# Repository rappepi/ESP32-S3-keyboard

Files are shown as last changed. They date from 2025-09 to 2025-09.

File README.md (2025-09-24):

# ESP32-S3-keyboard

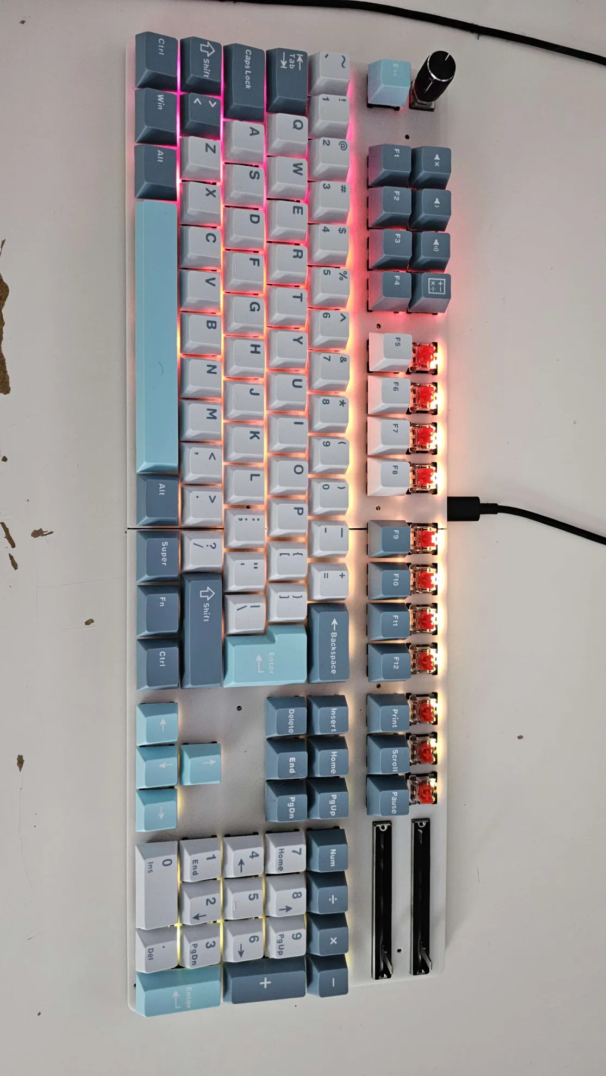
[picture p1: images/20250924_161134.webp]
PCB front view

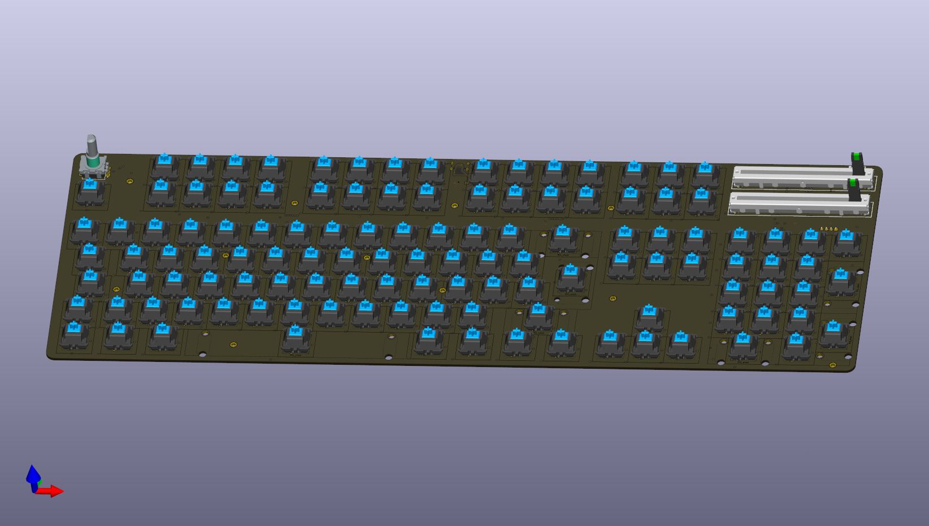
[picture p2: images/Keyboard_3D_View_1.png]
PCB 3D view 1

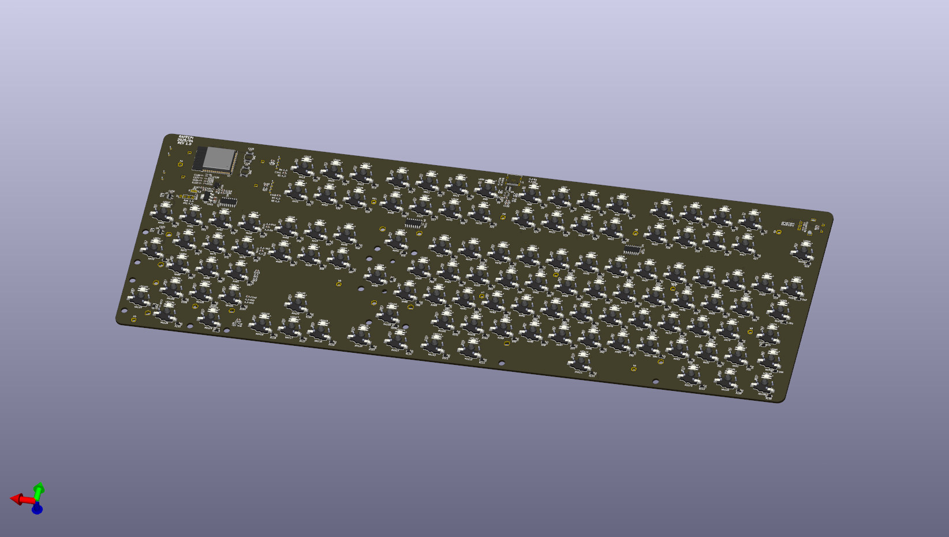
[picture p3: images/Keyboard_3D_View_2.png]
PCB 3D view 2


This project is licensed under the [Creative Commons Attribution-NonCommercial 4.0 International (CC BY-NC 4.0)](https://creativecommons.org/licenses/by-nc/4.0/).  
You are free to use, modify, and share the project as long as it is **not for commercial use** and **you give appropriate credit** to the original author.



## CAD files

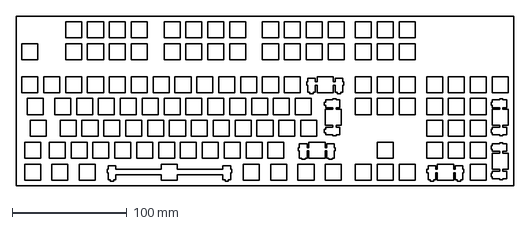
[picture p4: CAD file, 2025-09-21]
keyboard plate.dxf
433.6 x 147.8 mm

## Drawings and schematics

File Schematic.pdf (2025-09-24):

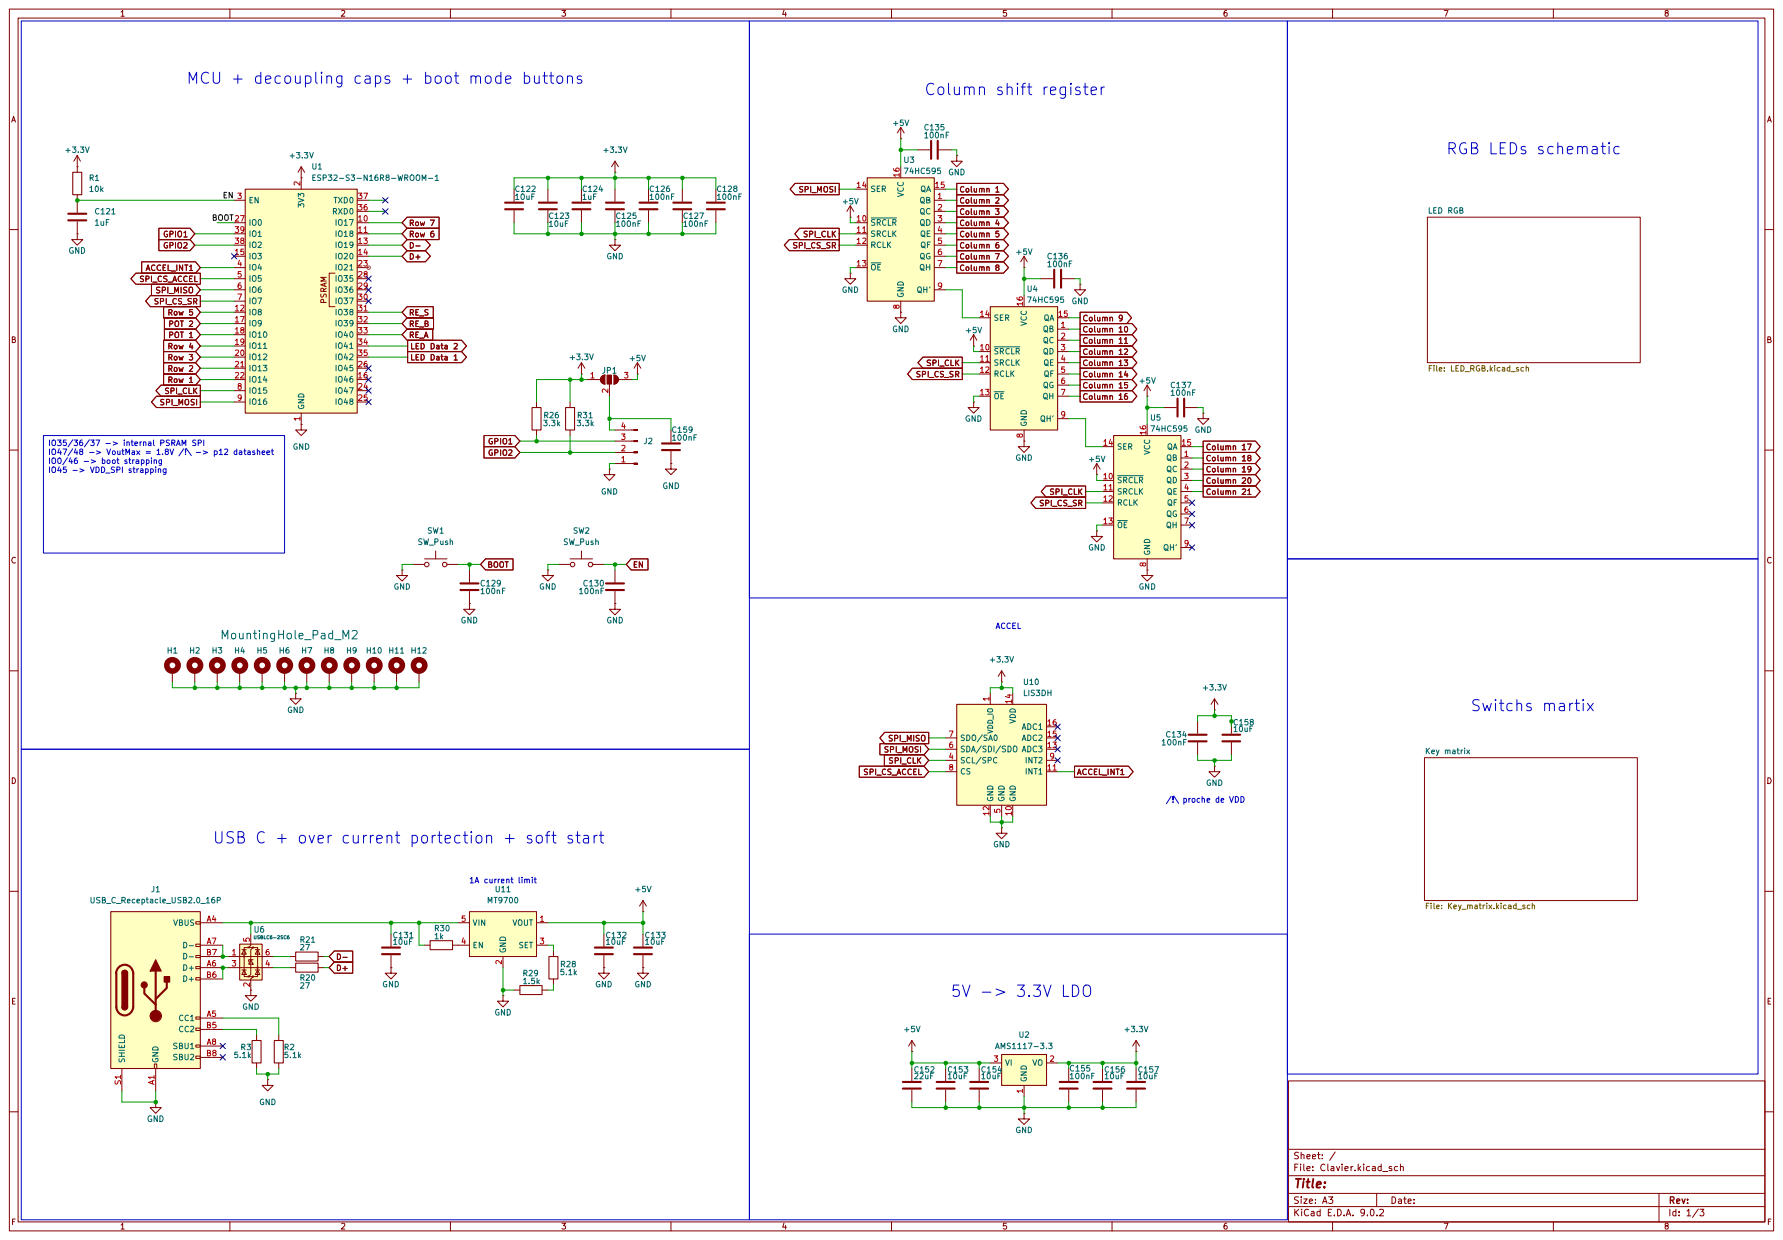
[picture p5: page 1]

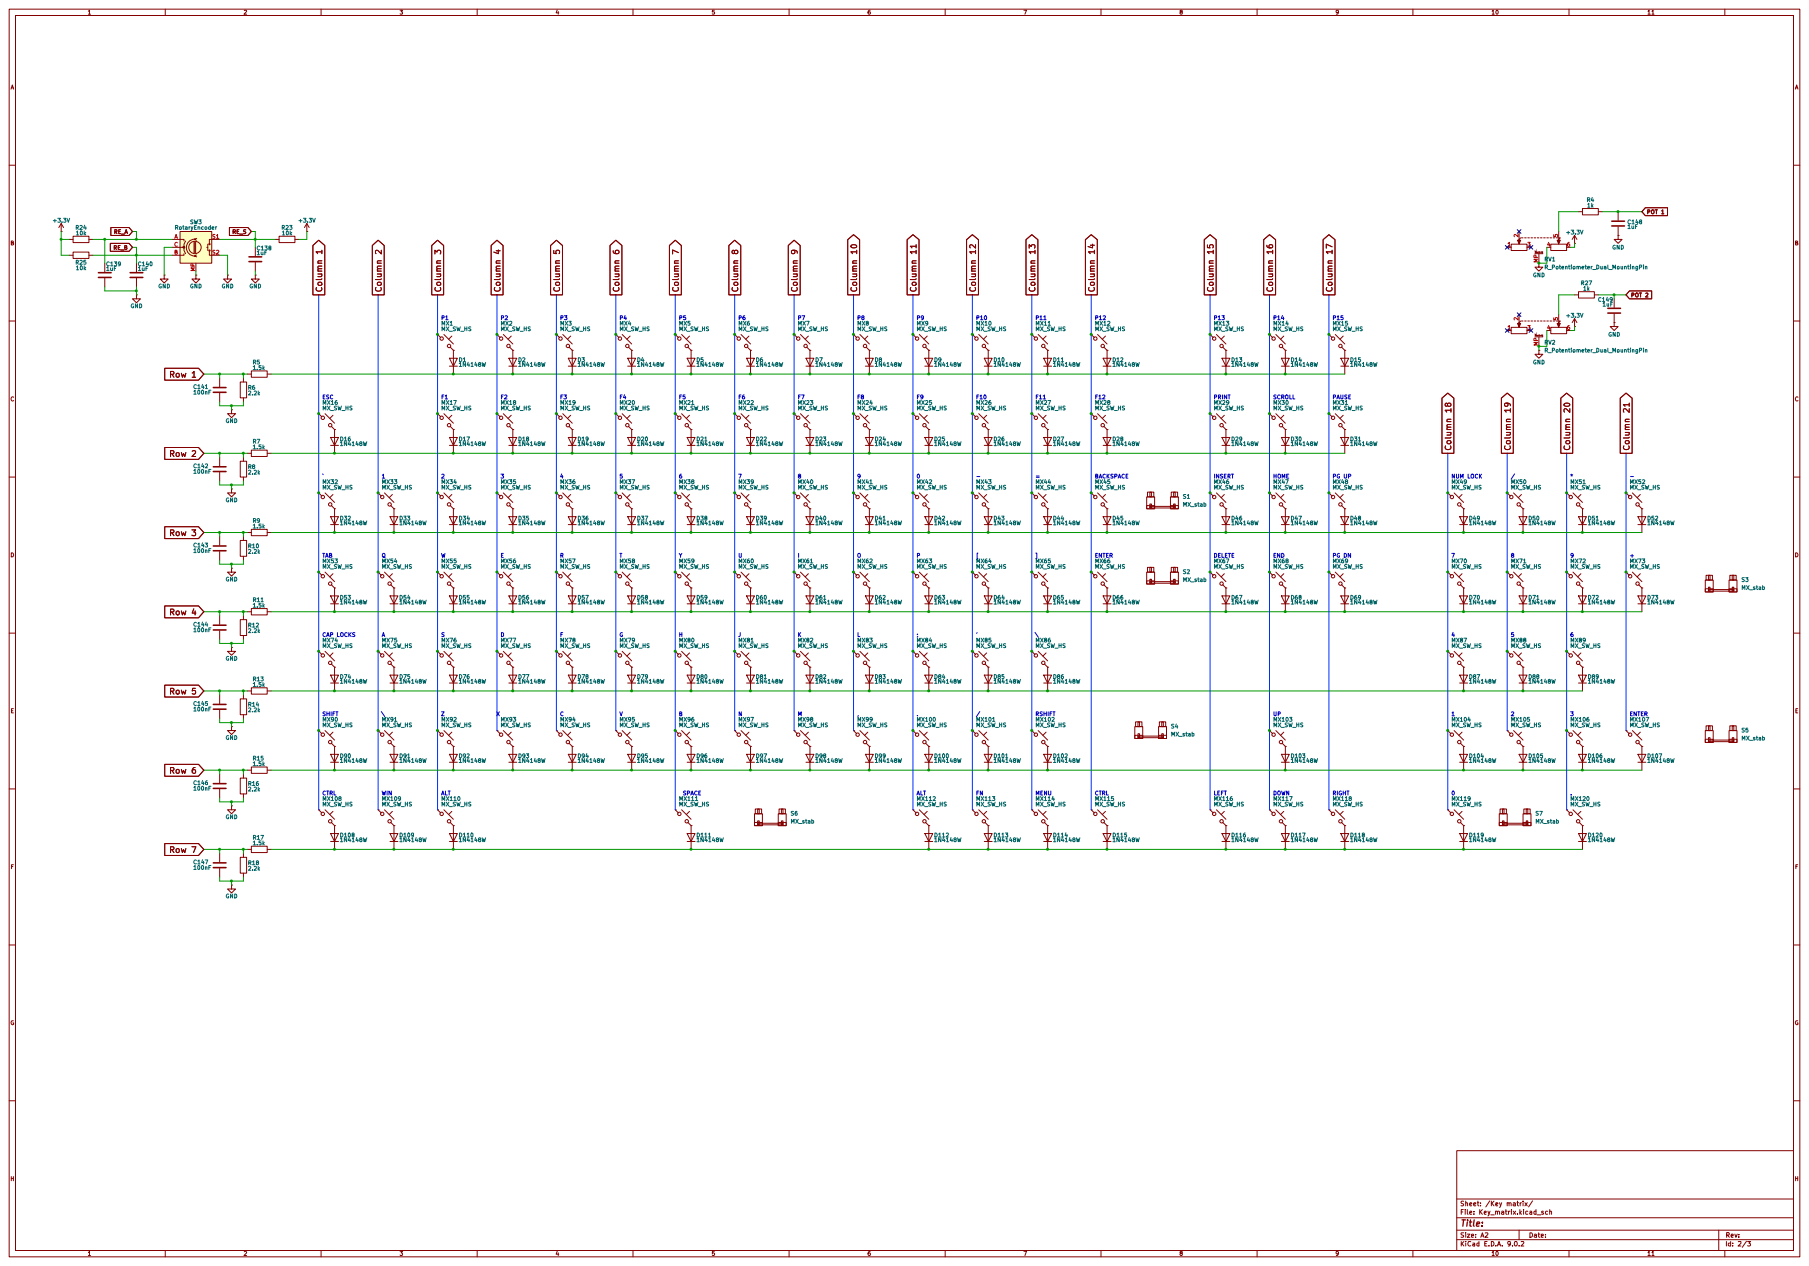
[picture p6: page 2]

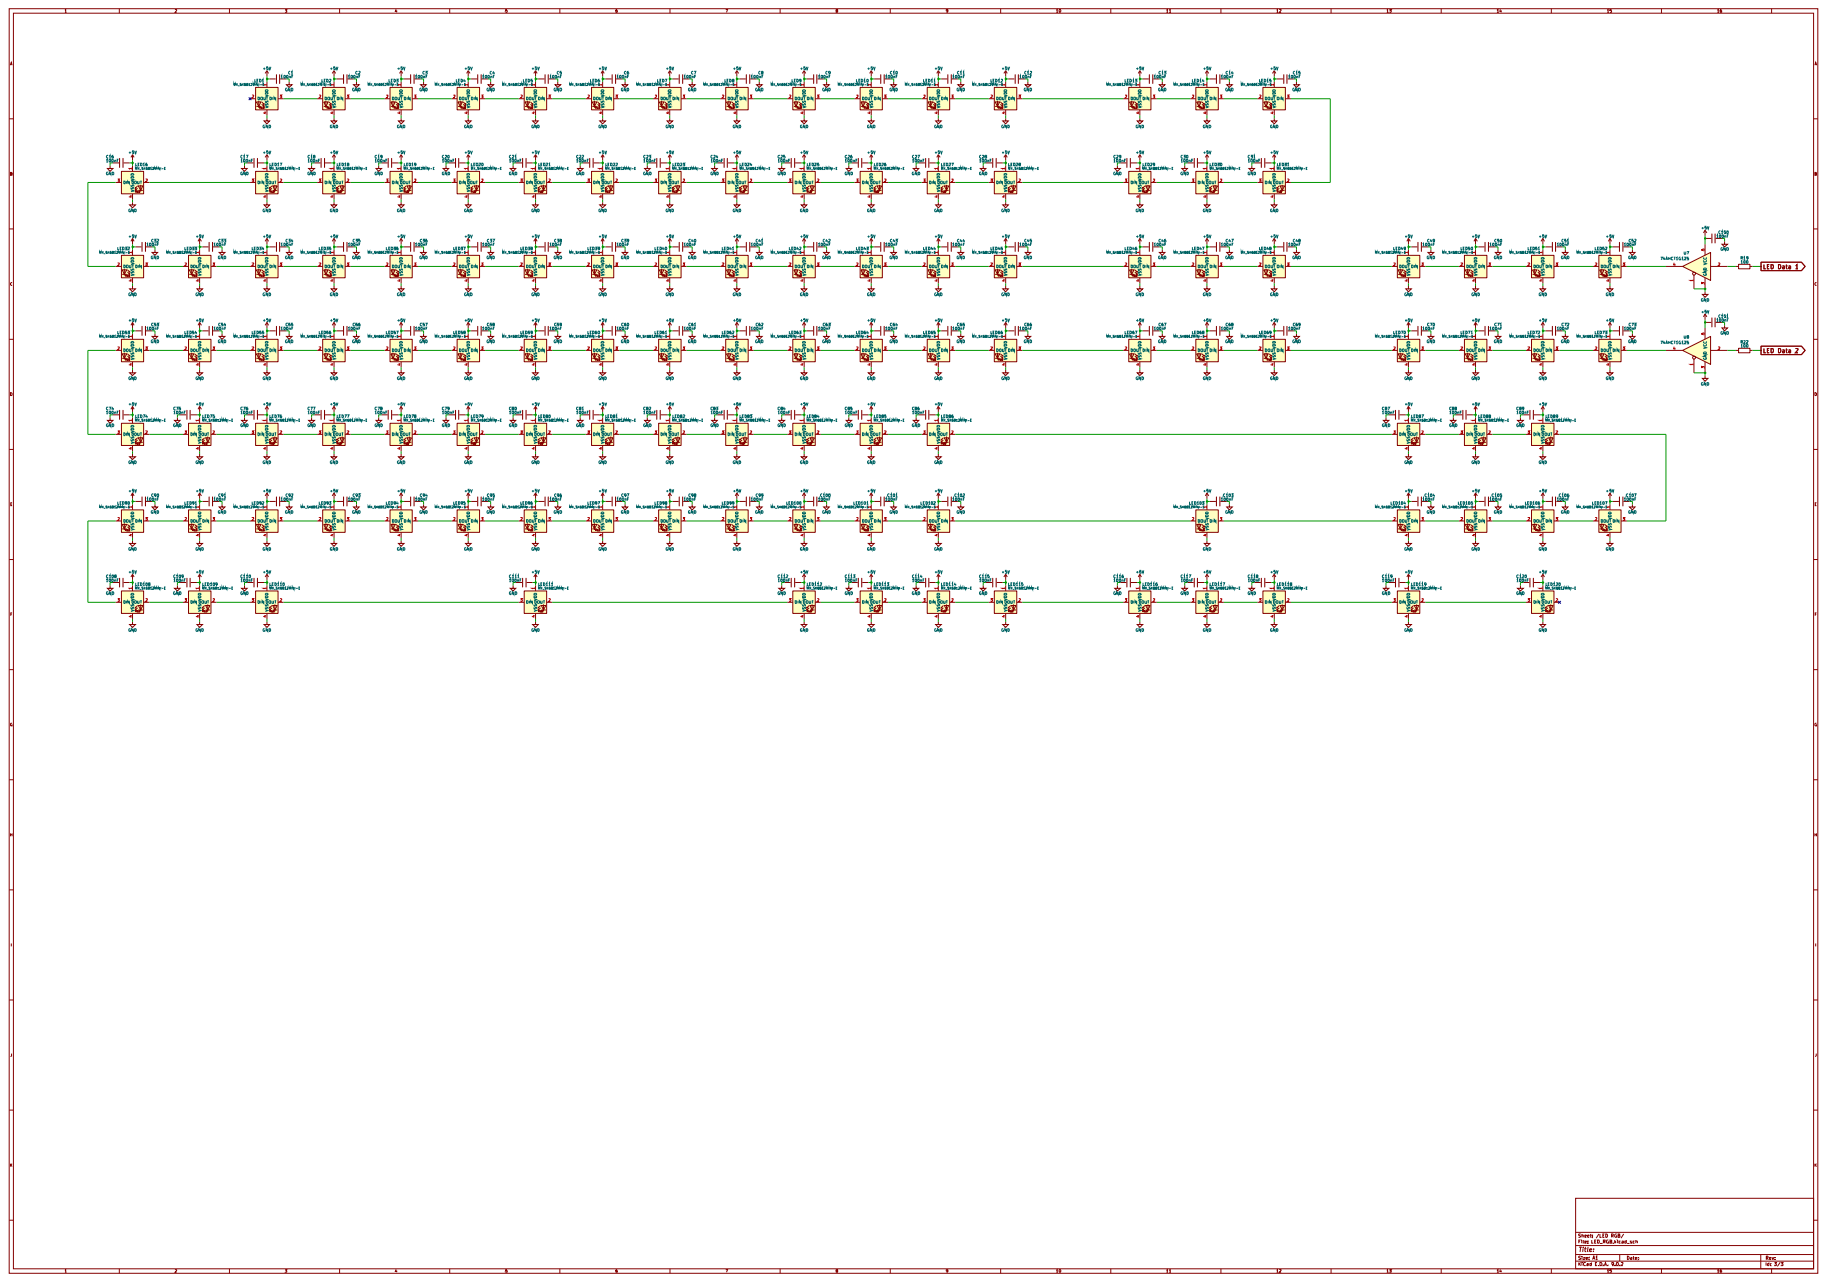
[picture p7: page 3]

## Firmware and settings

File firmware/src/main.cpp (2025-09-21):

#include "main.h"

SPIClass spi_bus(HSPI); //SPI3 voir https://github.com/espressif/arduino-esp32/issues/9588
Adafruit_LIS3DH accelerometer = Adafruit_LIS3DH(ACCELEROMETER_LATCH_PIN, &spi_bus, 1000000UL);

uint32_t last_frame_time;

USBHIDKeyboard keyboard;

CRGB leds[LED_COUNT];

typedef struct {
    uint32_t key_state;          //Key state after matrix scan
    uint32_t key_press_sent;      //Is the key press event sent
    uint32_t key_press_time;      //Last time the key had a key_state of 1
} keyboard_key_t;

keyboard_key_t keyboard_key_map[ROWS_COUNT][COLUMNS_COUNT] = {0};

// FAST LED I2S LED DRIVER
// https://github.com/FastLED/FastLED/blob/master/examples/Esp32S3I2SDemo/Esp32S3I2SDemo.h

void IRAM_ATTR update_encoder(){
    static bool encoder_clock_state, last_encoder_clock_state;
    encoder_clock_state = digitalRead(ENCODER_B_PIN);
    if(encoder_clock_state != last_encoder_clock_state){
        bool clock_wise = digitalRead(ENCODER_B_PIN) == encoder_clock_state;
    }
}

void IRAM_ATTR update_encoder_button(){
}

void select_column(uint8_t columns){
    uint32_t columns_mask = (uint32_t)1 << columns;
    FAST_WRITE_LOW(SHIFT_REGISTER_LATCH_PIN);
    //10Mhz is the max frequency usable because the signals are routed trought gpio matrix.
    //Any higher frequency like 20/40/80Mhz result in a unusable signal.
    spi_bus.transfer32(columns_mask);
    FAST_WRITE_HIGH(SHIFT_REGISTER_LATCH_PIN); 
    //Delay to let the signal settle. Without it will read last colums and not current one.
    for (uint8_t i = 0; i < 25; i++) {
        __asm__ __volatile__("nop");
    }
}

void enable_all_columns(){
    FAST_WRITE_LOW(SHIFT_REGISTER_LATCH_PIN);
    spi_bus.transfer32(0xFFFFFFFF);
    FAST_WRITE_HIGH(SHIFT_REGISTER_LATCH_PIN);     
    for (uint8_t i = 0; i < 25; i++) {
        __asm__ __volatile__("nop");
    }
}

void setup() {
    //Serial.begin(115200);
    //Implementer SERIAL pour envoyer commandes custom pour changer son spotify et windows via les potentiometres.
    //Possiblement mettre a jours le frameworks dans quelques jours https://github.com/espressif/arduino-esp32/issues/10307

    USB.begin();
    keyboard.begin();
    keyboard.pressRaw(KEY_NUMLOCK);

    attachInterrupt(ENCODER_A_PIN, update_encoder, CHANGE);
    attachInterrupt(ENCODER_B_PIN, update_encoder, CHANGE);
    attachInterrupt(ENCODER_BUTTON_PIN, update_encoder_button, FALLING);

    FastLED.addLeds<LED_TYPE, LED_PIN_1, GRB>(&leds[0],             LED_COUNT_1);
    FastLED.addLeds<LED_TYPE, LED_PIN_2, GRB>(&leds[LED_COUNT_1],   LED_COUNT_2);
    FastLED.setBrightness(DEFAULT_BRIGHTNESS);

    for(uint8_t i = 0; i < ARRAY_SIZE(rows_pin); i++) pinMode(rows_pin[i], INPUT);
    for (uint8_t i = 0; i < ARRAY_SIZE(input_pins); i++) pinMode(input_pins[i], INPUT);
    for (uint8_t i = 0; i < ARRAY_SIZE(output_pins); i++) pinMode(output_pins[i], OUTPUT);
    digitalWrite(ACCELEROMETER_LATCH_PIN, HIGH);
    digitalWrite(SHIFT_REGISTER_LATCH_PIN, HIGH);

    spi_bus.begin(SPI_CLOCK_PIN, SPI_MISO_PIN, SPI_MOSI_PIN, -1);

    accelerometer.begin();
    accelerometer.setRange(LIS3DH_RANGE_2_G);

}


void update_keyboard_matrix() {

    spi_bus.beginTransaction(SPISettings(10000000, MSBFIRST, SPI_MODE0));
    enable_all_columns();    

    //Reset the current key_state of the keyboard_key_map
    for (uint8_t column = 0; column < COLUMNS_COUNT; column++) {
        for (uint8_t row = 0; row < ROWS_COUNT; row++) {
            keyboard_key_map[row][column].key_state = 0;
        }
    }

    //If no inputs return because the keyboard_key_map will remain at 0.
    uint32_t rows_inputs = GPIO.in & rows_mask;
    if(rows_inputs == 0){
        spi_bus.endTransaction();
        return;
    }
    
    uint32_t time = (uint32_t)(esp_timer_get_time() / (uint64_t)1000);

    for (uint8_t column = 0; column < COLUMNS_COUNT; column++) {
        select_column(column);
        rows_inputs = GPIO.in & rows_mask;

        for (uint8_t row = 0; row < ROWS_COUNT; row++) {

            //Check if the current row has is key pressed
            if((rows_inputs & ((uint32_t)1 << rows_pin[row])) != 0){
                keyboard_key_map[row][column].key_state = 1;
                keyboard_key_map[row][column].key_press_time = time;
            }
        }
    }
    spi_bus.endTransaction();
    return;
}

void release_key(uint8_t row, uint8_t column){
    keyboard.releaseRaw(keyboard_map[row][column]);
    return;
}
void press_key(uint8_t row, uint8_t column){
    keyboard.pressRaw(keyboard_map[row][column]);
    return;
}

/*
    Asym Eager Defer debouce algorithms.
    If key is pressed and was not previously pressed, it will immediately send the pressed USB key.
    If key is released it will need to wait for debounce time to send the release key.
*/
void update_usb_key_state(){
    uint32_t time = (uint32_t)(esp_timer_get_time() / (uint64_t)1000);
    for (uint8_t column = 0; column < COLUMNS_COUNT; column++) {
        for (uint8_t row = 0; row < ROWS_COUNT; row++) {

            //Go to the next iteration if the key is not pressed and no usb key press has been sent.
            //Used to avoid doing a lot of if statments for all the unpressed keys.
            if(keyboard_key_map[row][column].key_state == 0 && keyboard_key_map[row][column].key_press_sent == 0){
                continue;
            }

            //Check if key is pressed
            if(keyboard_key_map[row][column].key_state == 1 && keyboard_key_map[row][column].key_press_sent == 0){
                keyboard_key_map[row][column].key_press_sent = 1;
                press_key(row, column); // KeyboardMap[row][column] for keycode
                continue;
            }

            //Check if key is released
            if(keyboard_key_map[row][column].key_state == 0 && keyboard_key_map[row][column].key_press_sent == 1){
                //Check if debounce timeout has elapsed
                if(keyboard_key_map[row][column].key_press_time + DEBOUNCE_TIME_MS <= time){
                    release_key(row, column); // KeyboardMap[row][column] for keycode
                    keyboard_key_map[row][column].key_press_sent = 0;
                }
            }
        }
    }
    return;
}

void loop() {
    update_keyboard_matrix();
    update_usb_key_state();
    
    uint32_t time = (uint32_t)(esp_timer_get_time() / (uint64_t)1000);
    if (now - last_frame_time >= LED_FRAME_INTERVAL_MS) {
        color_wave(leds);
        FastLED.show();
        last_frame_time = time;
    }
}

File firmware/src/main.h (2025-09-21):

#ifndef main_H
#define main_H
#include <SPI.h>
/*  USB HID  */
#include <USB.h>
#include <USBHIDKeyboard.h>
/*  Accelerometer  */
#include <Adafruit_LIS3DH.h>
#include <Adafruit_Sensor.h>
/*  Direct gpio access  */
#include "soc/gpio_struct.h"
/*  Commons functions  */
#include "utils.h"
/*  Keyboard  */
#include "keyboard_matrix_config.h"
#include "led_matrix_config.h"
/*  Led animation effects  */
#include <FastLED.h>
#include "led_animation/color_wave.h"

/*  SPI pin */
#define SPI_CLOCK_PIN     15
#define SPI_MOSI_PIN      16
#define SPI_MISO_PIN      6

/*  Accelerometer   */
#define ACCELEROMETER_LATCH_PIN         5
#define ACCELEROMETER_CLOCK_PIN         SPIClockPin
#define ACCELEROMETER_MOSI_PIN          SPIMOSIPin
#define ACCELEROMETER_MISO_PIN          SPIMISOPin
#define ACCELEROMETER_INTERRUPT_PIN     4
#define ACCELEROMETER_FREQUENCY         10000000

/*  Shift register  */
#define SHIFT_REGISTER_LATCH_PIN    7
#define SHIFT_REGISTER_DATA_PIN     SPIMOSIPin
#define SHIFT_REGISTER_CLOCK_PIN    SPIClockPin
#define SHIFT_REGISTER_FREQUENCY    10000000

/*  Rotary encoder  */
#define ENCODER_A_PIN           40
#define ENCODER_B_PIN           39      
#define ENCODER_BUTTON_PIN      38 

/*  Potentiometer pin  */
#define POTENTIOMETER_1_PIN     10
#define POTENTIOMETER_2_PIN     9

const uint8_t output_pins[] = {ACCELEROMETER_LATCH_PIN, SHIFT_REGISTER_LATCH_PIN};

const uint8_t input_pins[] = {ACCELEROMETER_INTERRUPT_PIN, ENCODER_A_PIN, ENCODER_B_PIN, ENCODER_BUTTON_PIN, POTENTIOMETER_1_PIN, POTENTIOMETER_2_PIN};

#endif

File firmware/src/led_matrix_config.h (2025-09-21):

#ifndef ledMatrixConfig_H
#define ledMatrixConfig_H

#include <stdint.h>

#define LED_PIN_1       42
#define LED_PIN_2       41
#define LED_COUNT_1     52
#define LED_COUNT_2     68
#define LED_COUNT       (LED_COUNT_1 + LED_COUNT_2)
#define LED_TYPE        SK6812

#define LED_ROWS_COUNT      7
#define LED_COLUMNS_COUNT   21

#define DEFAULT_BRIGHTNESS      50
#define LED_FRAME_RATE          30
#define LED_FRAME_INTERVAL_MS   (1000/LED_FRAME_RATE)

const uint8_t LedMap[LED_ROWS_COUNT][LED_COLUMNS_COUNT] = {        //255 means no led (spacing)
    //Row 1
    {255, 255, 51, 50, 49, 48, 47, 46, 45, 44, 43, 42, 41, 40, 39, 38, 37, 255, 255, 255, 255},
    //Row 2
    {21, 255, 22, 23, 24, 25, 26, 27, 28, 29, 30, 31, 32, 33, 34, 35, 36, 255, 255, 255, 255},
    //Row 3
    {20, 19, 18, 17, 16, 15, 14, 13, 12, 11, 10, 9, 8, 7, 6, 5, 4, 3, 2, 1, 0},
    //Row 4
    {72, 71, 70, 69, 68, 67, 66, 65, 64, 63, 62, 61, 60, 59, 58, 57, 56, 55, 54, 53, 52},
    //Row 5
    {73, 74, 75, 76, 77, 78, 79, 80, 81, 82, 83, 84, 85, 255, 255, 255, 255, 86, 87, 88, 255},
    //Row 6
    {106, 105, 104, 103, 102, 101, 100, 99, 98, 97, 96, 95, 94, 255, 255, 93, 255, 92, 91, 90, 89},
    //Row 7
    {107, 108, 109, 255, 255, 255, 110, 255, 255, 255, 111, 112, 113, 114, 115, 116, 117, 118, 255, 119, 255}
};

#endif

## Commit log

2025-09-21 Inital commit
    [Clavier-B_Cu.gbr, Clavier-B_Mask.gbr, Clavier-B_Paste.gbr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]
2025-09-24 Added readme, license, schematic, and image

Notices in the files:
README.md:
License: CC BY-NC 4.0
